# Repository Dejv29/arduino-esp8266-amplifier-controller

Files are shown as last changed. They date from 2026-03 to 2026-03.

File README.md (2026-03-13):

## **arduino-esp8266-amplifier-controller**  

Hybrid analog/digital amplifier controller with IR learning, motorized ALPS potentiometer feedback and ESP8266 web API.

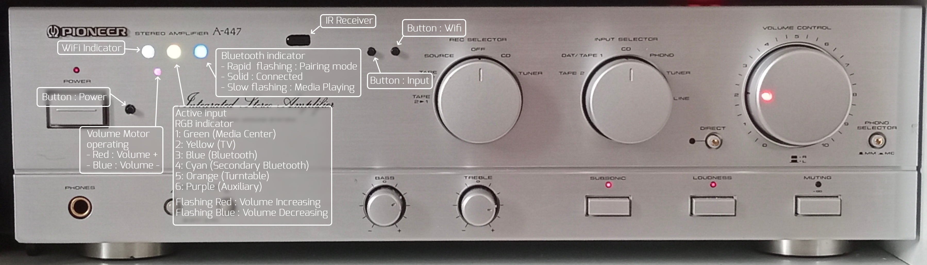
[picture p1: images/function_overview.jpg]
Amplifier


# **Arduino + ESP8266 Amplifier Controller**  

This project is a comprehensive control system for a classic analog amplifier built using an Arduino Nano and ESP8266. The goal was to preserve the original analog character of the amplifier (including manual volume control) while adding modern features such as IR control, a web interface, a remote terrace panel, and a network API.  

The module is designed as an upgrade for a previous system based on the CD4017N microcontroller. The PCB is connected to a socket in place of the CD4017N.

### **Architecture**

The system is divided into two parts:  

#### **Arduino Nano**  

- Control of the ALPS motorized potentiometer (volume)  

- Reading the current position of the rotary volume knob via an analog input (with an added trim potentiometer for feedback)  

- IR receiver with the ability to learn up to 10 codes for each function (stored in EEPROM)  

- Control of input relays and speaker switching relays  

- RGB LED indication of the currently selected input  

#### **ESP8266**

- Web server with configuration and control interface  

- HTTP API for external control  

- Serial communication with the Arduino  

Both parts operate independently – a WiFi outage does not affect the basic functionality of the amplifier.  

### **Features**

#### **IR Learning (EEPROM)**  

Each function can have up to 10 different IR codes assigned:  

- Volume +  
- Volume -  
- Power  
- Input  
- Speakers  
- Media Play/Pause  
- Media Next  
- Media Previous  

This allows multiple remote controls to be used simultaneously.  

#### **Volume – Hybrid Solution**  

An ALPS motorized potentiometer is used.  

Analog position sensing has been added, which means:  

- the volume can be adjusted by the motor (IR, web, HW buttons)  
- it can also be changed manually by turning the knob  
- the Arduino always knows the current physical position  

This preserves full analog functionality while adding digital control.  

#### **Audio Inputs**  

- 6 inputs  
- RGB LED indicates the active input  
- Input 3 contains an internal Bluetooth module  
- Input 4 contains an external Bluetooth module located in the terrace panel  

Each input can have an individual maximum volume limit set to prevent speaker overload when different signal levels are used.  

#### **Speaker Switching**  

The **Speakers** function switches between:  

- Living room speakers  
- Terrace speakers  

#### **Terrace Control Panel**  

The external panel includes:  

- Hardware buttons for all functions  
- A rotary volume control  
- An IR receiver  

The amplifier can therefore be fully controlled even outside the main room.  

#### **Web Interface (ESP8266)**  

The ESP8266 runs a simple web server that allows:  

- Control of all amplifier functions  
- Learning and deleting IR codes  
- Setting maximum volume limits for individual inputs  
- Displaying the current device status  

#### **HTTP API**  

The server accepts commands in the following format:  

SET_POWER_ON / SET_POWER_OFF  

SET_VOLUME_25  

SET_INPUT_2  

SET_SPEAKER_A / SET_SPEAKER_B  

PULSE_VOLUP  

PULSE_VOLDOWN  

SET_AUTO_OFF_<value_in_seconds> / SET_AUTO_OFF_0 – cancels the timer  

IR_LEARN_POWER (VOLUP, VOLDOWN, INPUT, SPEAKERS, PLAY, NEXT, PREV)  

IR_REMOVE_POWER (VOLUP, VOLDOWN, INPUT, SPEAKERS, PLAY, NEXT, PREV )  

IR_REMOVE_POWER_ALL  

SET_MAX_VOL_INPUT__<volume_value>   (sets the specified volume value as the limit)

SET_CURRENT_MAX_VOLUME  (sets the current volume as the limit)

WIPE_EEPROM (clears the EEPROM memory)

Each request returns a response containing the complete current device status.  

This API can be easily integrated into other systems – for example into the **Tasker** app, where a simple control application using HTTP commands has been created.  

____________________________________________________________________________________________________________________________________________________________________________________________________________________________________________________________________________________________________________________________________________

# **Arduino + ESP8266 Amplifier Controller**  

Tento projekt je komplexní řídicí systém pro klasický analogový zesilovač postavený na Arduino Nano a  ESP8266. Cílem bylo zachovat původní analogový charakter zesilovače (včetně manuálního ovládání hlasitosti), ale doplnit jej o moderní funkce – IR ovládání, webové rozhraní, vzdálený panel na terase a síťové API. 

Modul je koncipován jako upgrade pro předchozí systém postavený na mikrokontroléru CD4017N. PCB je připojena do patice na místo CD4017N.

### **Architektura**

Systém je rozdělen na dvě části:  

#### **Arduino Nano**  

- Řízení motorizovaného potenciometru ALPS (hlasitost)  

- Snímání aktuální polohy otočného ovladače hlasitosti přes analogový vstup (přidaný trimr pro zpětnou vazbu)  

- IR přijímač s možností učení až 10 kódů na každou funkci (uloženo v EEPROM)  

- Ovládání relé vstupů a reproduktorových větví  

- RGB LED indikace aktuálního vstupu  

#### **ESP8266**

- Web server s konfiguračním a ovládacím rozhraním  

- HTTP API pro externí řízení  

- Sériová komunikace s Arduinem 

 Obě části fungují nezávisle – výpadek WiFi neovlivní základní funkčnost zesilovače.  

### **Funkce**

#### **IR učení (EEPROM)**  

Každé funkci lze přiřadit až 10 různých IR kódů:  

- Volume +  
- Volume -  
- Power  
- Input  
- Speakers  
- Media Play/Pause  
- Media Next  
- Media Previous  

To umožňuje používat více dálkových ovladačů současně.  

#### **Hlasitost – hybridní řešení**  

Použit je motorizovaný potenciometr ALPS.  

   Bylo doplněno analogové snímání polohy, takže:  
- hlasitost lze měnit motorem (IR, web, HW tlačítka)  
- lze ji měnit i ručně otočením knobu  
- Arduino vždy zná aktuální fyzickou polohu

 Zachována je tedy plná analogová funkčnost, ale s digitální kontrolou.  

#### **Audio vstupy**  

- 6 vstupů  
- RGB LED indikuje aktivní vstup  
- Na vstupu 3 je interní Bluetooth modul  
- Na vstupu 4 je externí Bluetooth modul umístěný v terasovém panelu  

 Pro každý vstup lze nastavit individuální maximální limit hlasitosti, aby nedošlo k přetížení reproduktorů při různých úrovních signálu.  

#### **Přepínání reproduktorů**  

Funkce **Speakers** přepíná mezi:  

- Reproduktory v obýváku  
- Reproduktory na terase  

#### **Terasový ovládací panel**  

Externí panel obsahuje:  

- HW tlačítka pro všechny funkce  
- Otočný ovladač hlasitosti  
- IR přijímač  

 Zesilovač je tedy plně ovladatelný i mimo hlavní místnost.  

#### **Webové rozhraní (ESP8266)**  

ESP8266 provozuje jednoduchý web server, který umožňuje:  

- Ovládání všech funkcí zesilovače  
- Učení a mazání IR kódů  
- Nastavení maximální hlasitosti pro jednotlivé vstupy  
- Zobrazení aktuálního stavu zařízení  

#### **HTTP API**  

Server přijímá příkazy ve formátu:  

SET_POWER_ON / SET_POWER_OFF  

SET_VOLUME_25  

SET_INPUT_2  

SET_SPEAKER_A / SET_SPEAKER_B

PULSE_VOLUP  

PULSE_VOLDOWN  

SET_AUTO_OFF_<hodnota_v_sekundách> / SET_AUTO_OFF_0 – zruší časovač 

IR_LEARN_POWER (VOLUP, VOLDOWN, INPUT, SPEAKERS, PLAY, NEXT, PREV)  

IR_REMOVE_POWER (VOLUP, VOLDOWN, INPUT, SPEAKERS, PLAY, NEXT, PREV )  

IR_REMOVE_POWER_ALL  

SET_MAX_VOL_INPUT__<hodnota_volume>   (nastaví zadanou hodnotu hlasitosti jako limit)

SET_CURRENT_MAX_VOLUME  (nastaví současnou hlasitost jako limit)

WIPE_EEPROM (vymaže paměť EEPROM)

 Každý požadavek vrací odpověď obsahující kompletní aktuální stav zařízení.  

 Toto API lze snadno integrovat do jiných systémů – například do aplikace **Tasker**, kde je vytvořena jednoduchá ovládací aplikace využívající HTTP příkazy

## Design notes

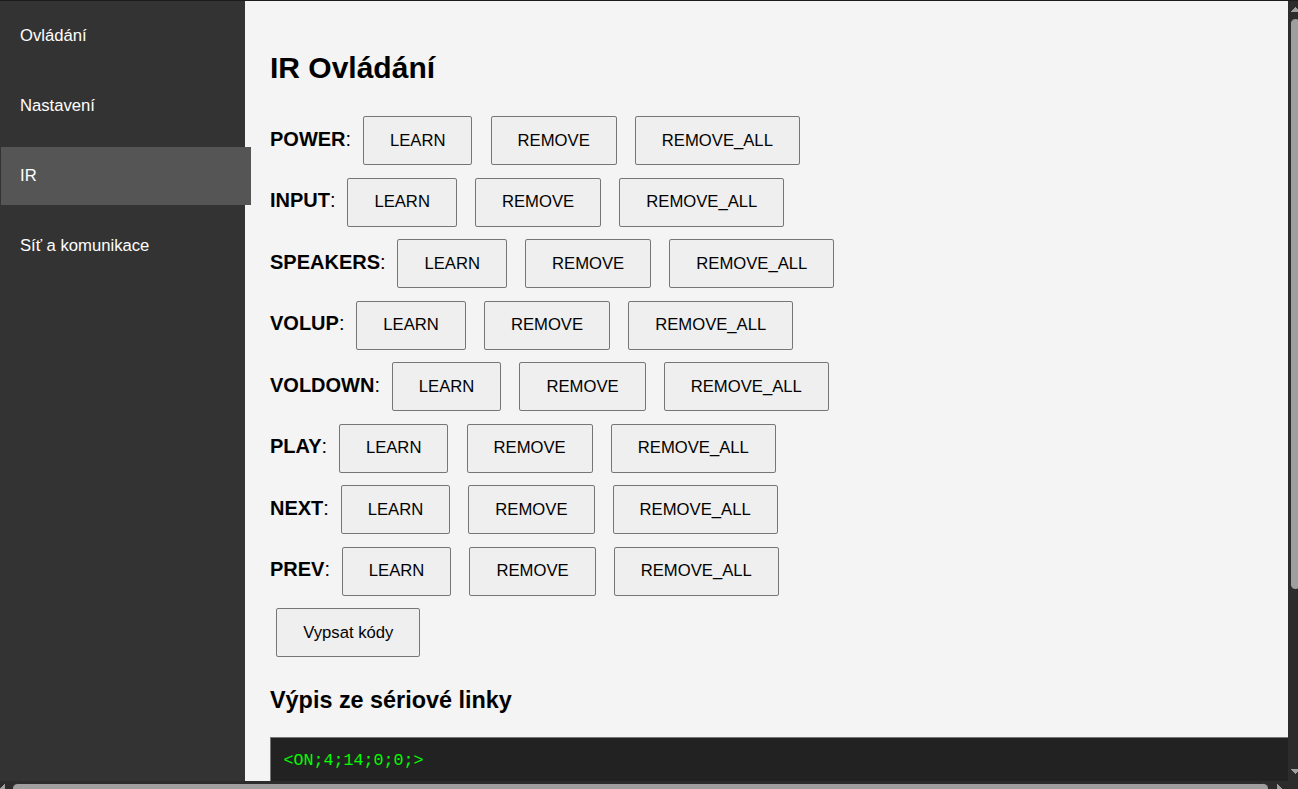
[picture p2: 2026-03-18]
images/web-ui_03.png

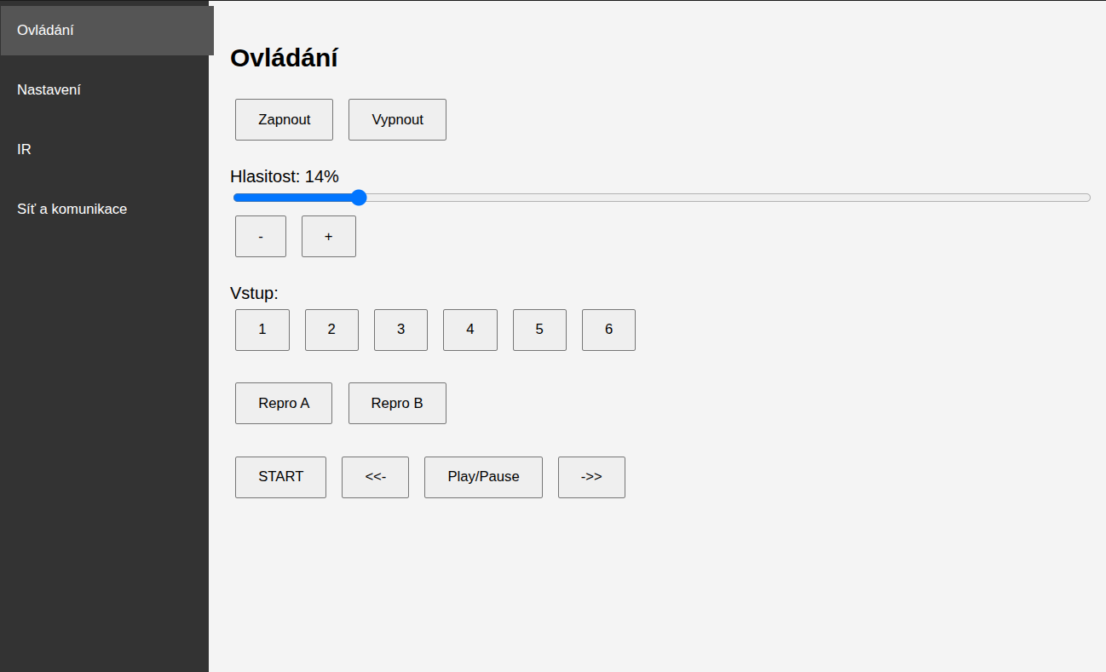
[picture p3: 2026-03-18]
images/web-ui_01.png

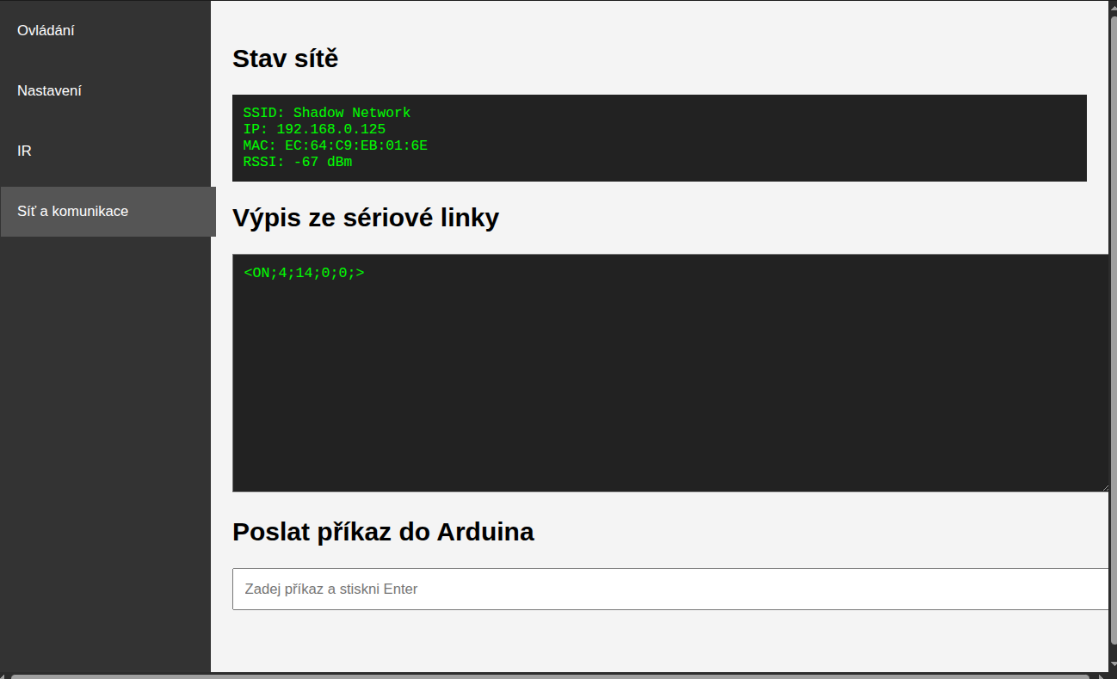
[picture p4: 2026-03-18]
images/web-ui_04.png

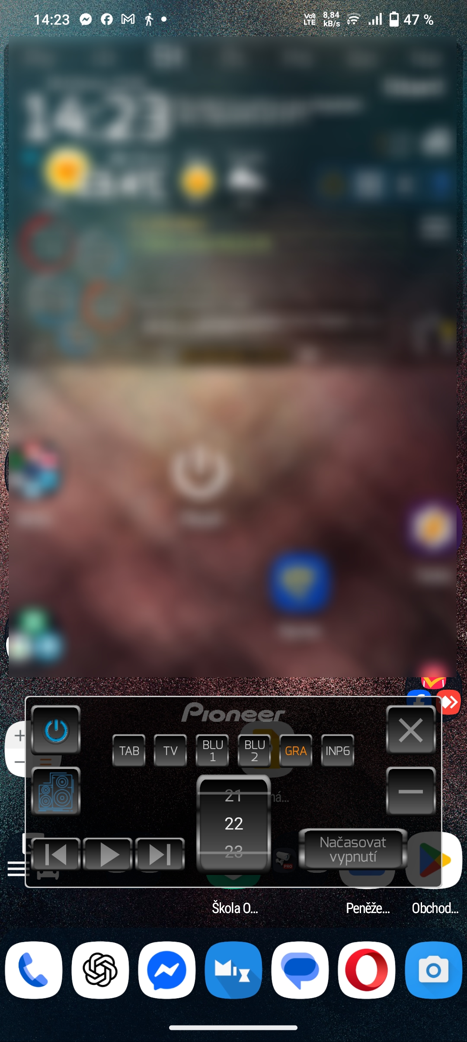
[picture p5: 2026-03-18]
images/tasker_control_ui.jpg

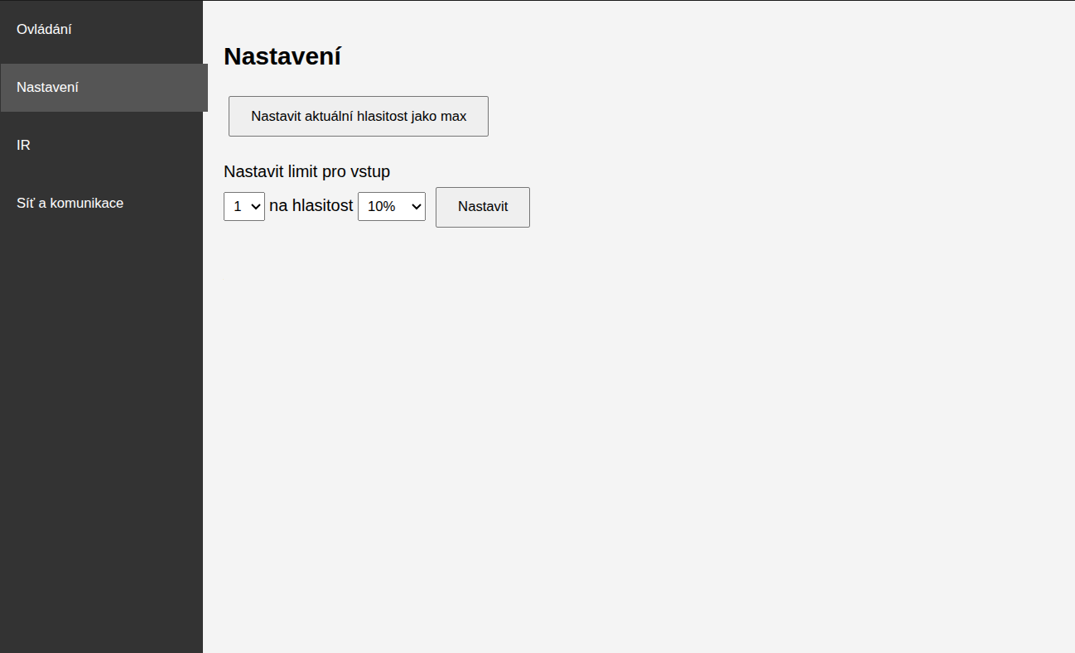
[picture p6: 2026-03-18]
images/web-ui_02.png

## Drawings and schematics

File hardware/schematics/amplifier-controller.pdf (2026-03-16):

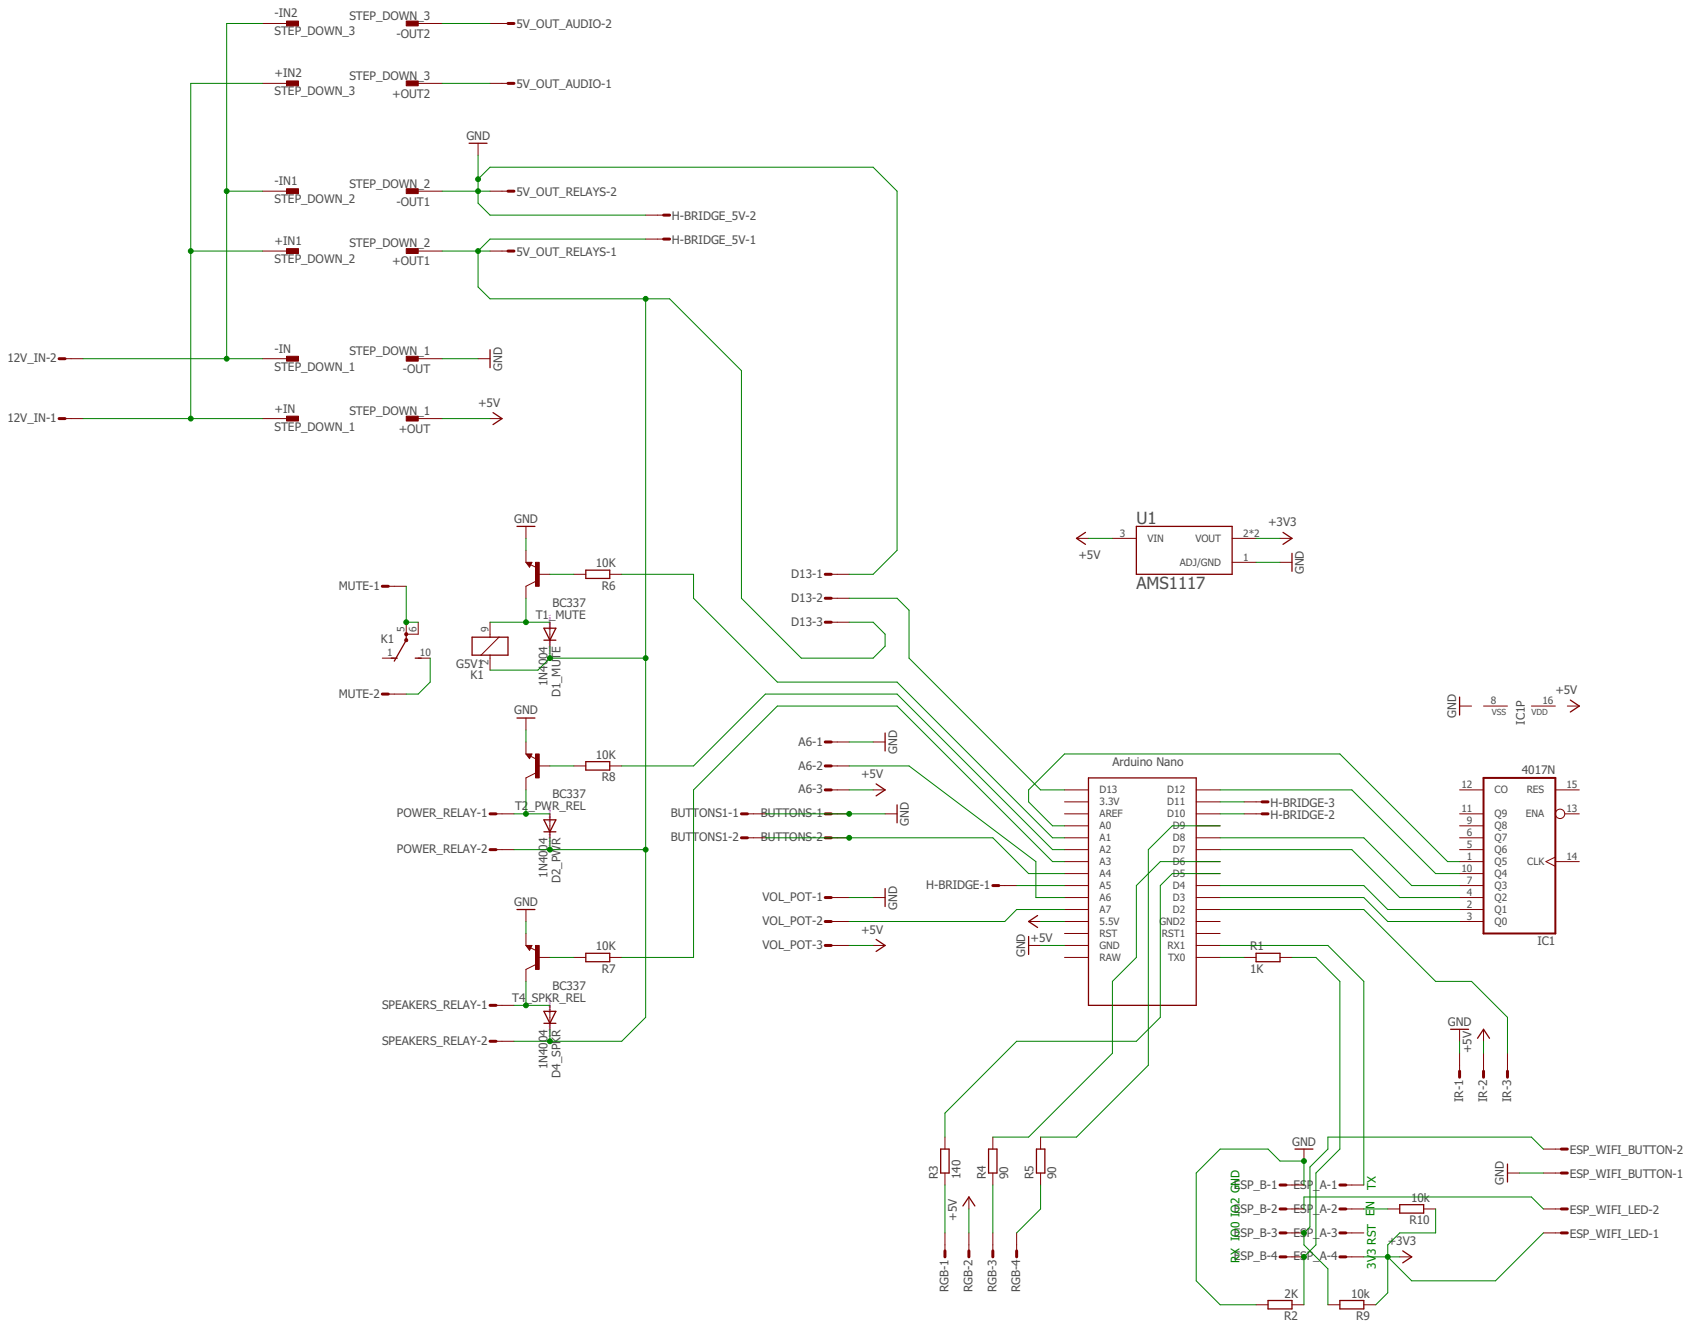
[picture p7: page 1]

SpiceOrder 1 SpiceOrder 2 SpiceOrder 1 SpiceOrder 2 SpiceOrder 1 SpiceOrder 2

RGB-1 RGB-2 RGB-3 RGB-4

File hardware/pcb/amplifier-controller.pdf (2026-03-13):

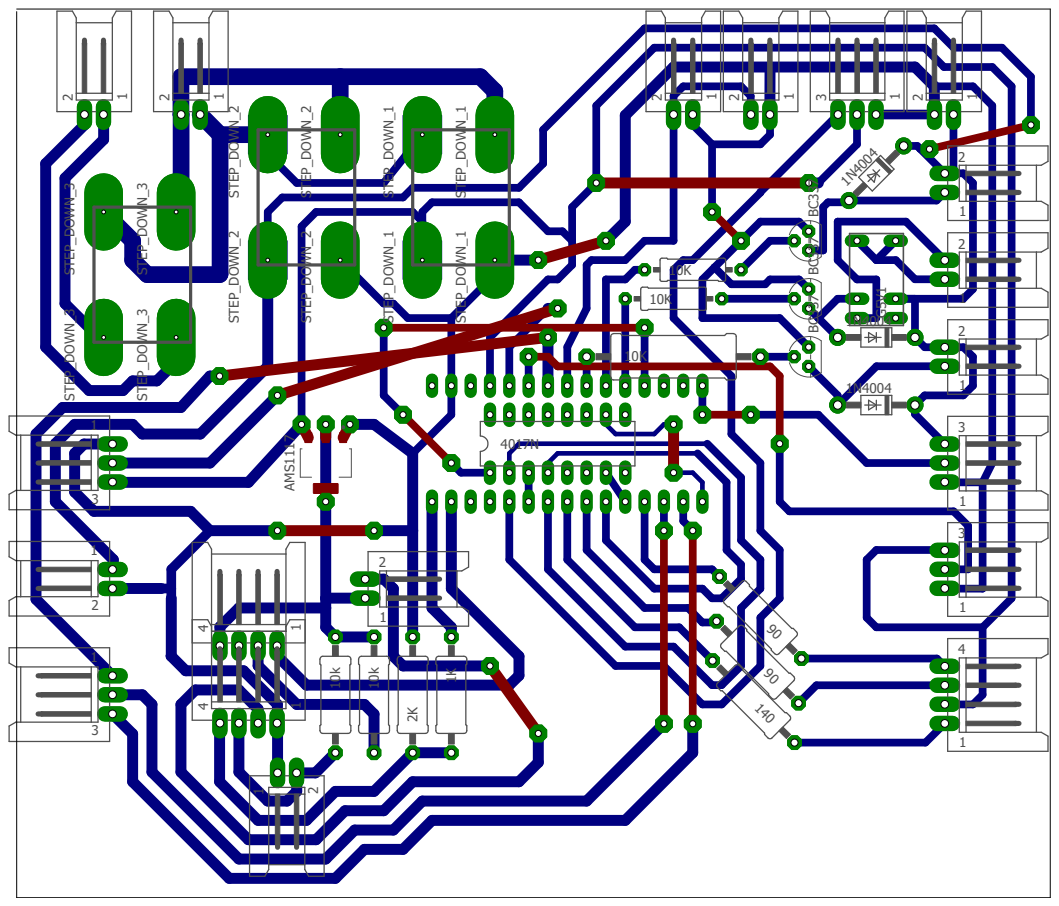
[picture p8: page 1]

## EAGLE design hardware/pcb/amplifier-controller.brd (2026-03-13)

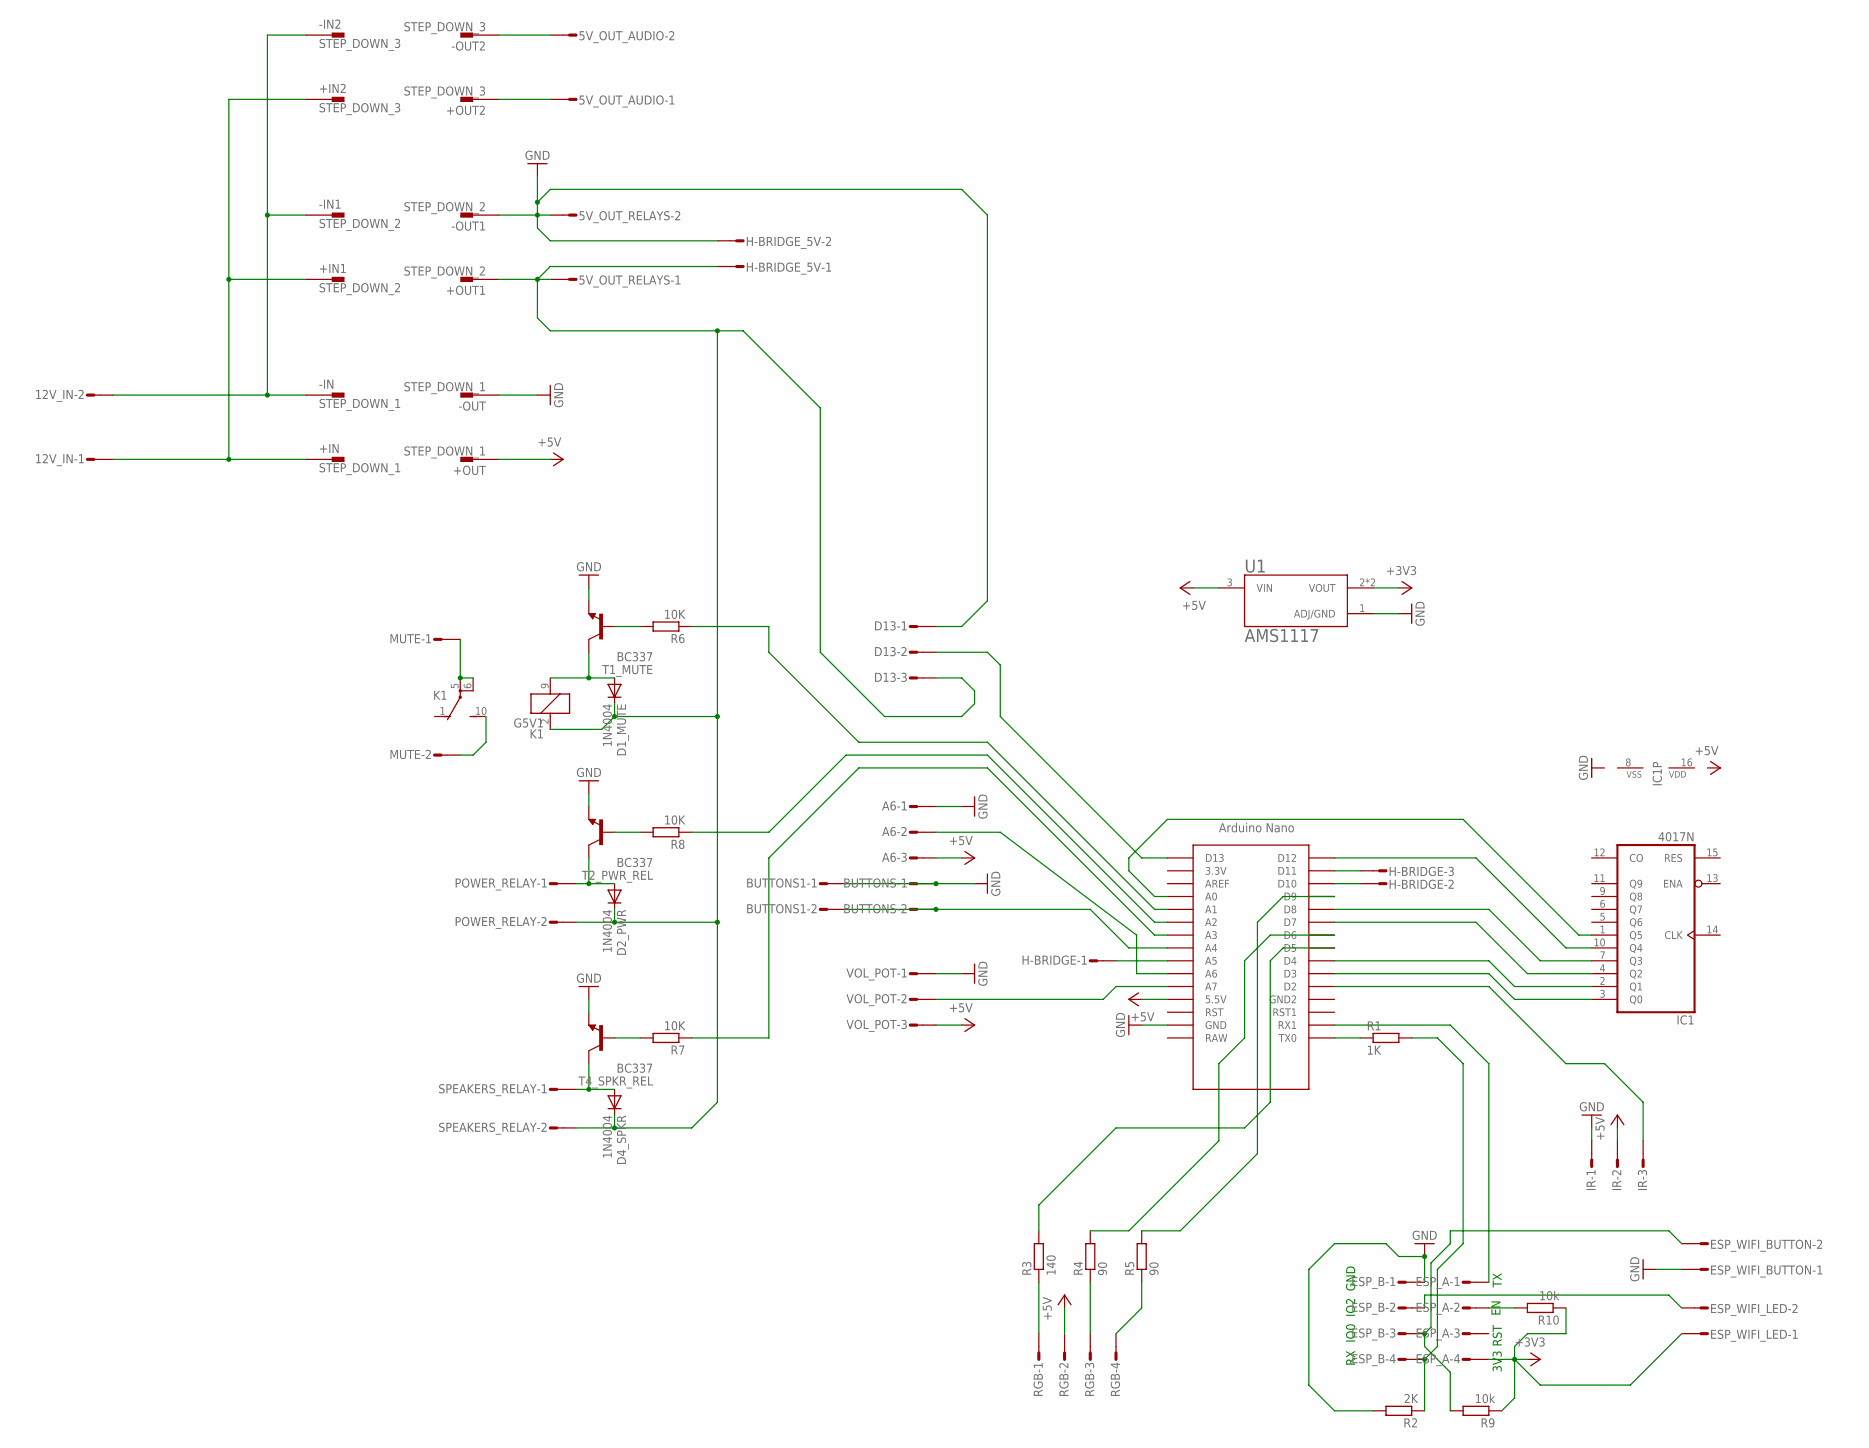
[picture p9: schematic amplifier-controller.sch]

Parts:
5V_OUT_AUDIO, 5V_OUT_RELAYS, 12V_IN: L02P
+IN: STEP_DOWN_1; 62221
+IN1: STEP_DOWN_2; 62221
+IN2: STEP_DOWN_3; 62221
+OUT: STEP_DOWN_1; 62221
+OUT1: STEP_DOWN_2; 62221
+OUT2: STEP_DOWN_3; 62221
-IN: STEP_DOWN_1; 62221
-IN1: STEP_DOWN_2; 62221
-IN2: STEP_DOWN_3; 62221
-OUT: STEP_DOWN_1; 62221
-OUT1: STEP_DOWN_2; 62221
-OUT2: STEP_DOWN_3; 62221
A6: L03P
BUTTONS, BUTTONS1: L02P
D1_MUTE, D2_PWR, D4_SPKR: 1N4004; DO41-10
D13: L03P
ESP_A: L04P
ESP_B: L04P
ESP_WIFI_BUTTON: L02P
ESP_WIFI_LED: L02P
H-BRIDGE: L03P
H-BRIDGE_5V: L02P
IC1: 4017N; DIL16
IR: L03P
K1: G5V1
MUTE: L02P
POWER_RELAY: L02P
R1: 1K; 0411/15
R2: 2K; 0411/15
R3: 140; 0411/15
R4, R5: 90; 0411/15
R6, R8: 10K; 0309/12
R7: 10K; 0617/22
R9, R10: 10k; 0411/15
RGB: L04P
SPEAKERS_RELAY: L02P
T1_MUTE, T2_PWR_REL, T4_SPKR_REL: BC337; TO92
U1: AMS1117; SOT229P700X180-4N
U$1: NANO
VOL_POT: L03P

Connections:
+3V3: ESP_A.4, ESP_WIFI_LED.1, R9.1, R10.1, U1.2 (VOUT), U1.4 (VOUT)
+5V: +OUT.1, A6.3, IR.2, RGB.2, U1.3 (VIN), U$1.5V (5.5V), VOL_POT.3
GND: 5V_OUT_RELAYS.2, -OUT.1, -OUT1.1, A6.1, BUTTONS.1, BUTTONS1.1, D13.1, ESP_B.1, ESP_WIFI_BUTTON.1, H-BRIDGE_5V.2, IR.1, R2.2, T1_MUTE.1 (E), T2_PWR_REL.1 (E), T4_SPKR_REL.1 (E), U1.1 (ADJ/GND), U$1.GND, VOL_POT.1
unnamed: ESP_B.4, R1.2, R2.1
unnamed: R1.1, U$1.TX0
unnamed: IR.3, U$1.D2
unnamed: IC1.3 (Q0), U$1.D3
unnamed: IC1.2 (Q1), U$1.D4
unnamed: IC1.4 (Q2), U$1.D7
unnamed: IC1.7 (Q3), U$1.D8
unnamed: IC1.10 (Q4), U$1.D12
unnamed: IC1.1 (Q5), U$1.A0
unnamed: H-BRIDGE.1, U$1.A5
unnamed: H-BRIDGE.2, U$1.D10
unnamed: H-BRIDGE.3, U$1.D11
unnamed: U$1.A7, VOL_POT.2
unnamed: BUTTONS.2, BUTTONS1.2, U$1.A4
unnamed: R3.1, RGB.1
unnamed: R4.1, RGB.3
unnamed: R5.1, RGB.4
unnamed: R3.2, U$1.D5
unnamed: R4.2, U$1.D6
unnamed: R5.2, U$1.D9
unnamed: D13.2, U$1.D13
unnamed: A6.2, U$1.A6
unnamed: ESP_B.3, ESP_WIFI_BUTTON.2, R9.2
unnamed: ESP_A.1, U$1.RX1
unnamed: D4_SPKR.A, SPEAKERS_RELAY.1, T4_SPKR_REL.3 (C)
unnamed: R7.2, T4_SPKR_REL.2 (B)
unnamed: R6.2, T1_MUTE.2 (B)
unnamed: R6.1, U$1.A1
unnamed: R7.1, U$1.A3
unnamed: D1_MUTE.A, K1.9 (2), T1_MUTE.3 (C)
unnamed: R8.2, T2_PWR_REL.2 (B)
unnamed: R8.1, U$1.A2
unnamed: D2_PWR.A, POWER_RELAY.1, T2_PWR_REL.3 (C)
unnamed: ESP_A.2, R10.2
unnamed: 12V_IN.2, -IN.1, -IN1.1, -IN2.1
unnamed: ESP_B.2, ESP_WIFI_LED.2
unnamed: 12V_IN.1, +IN.1, +IN1.1, +IN2.1
unnamed: K1.5, K1.6, MUTE.1
unnamed: K1.10 (S), MUTE.2
unnamed: 5V_OUT_AUDIO.1, +OUT2.1
unnamed: 5V_OUT_AUDIO.2, -OUT2.1
unnamed: 5V_OUT_RELAYS.1, +OUT1.1, D1_MUTE.C, D2_PWR.C, D4_SPKR.C, D13.3, H-BRIDGE_5V.1, K1.2 (1), POWER_RELAY.2, SPEAKERS_RELAY.2
VDD: IC1.16 (VDD)
VSS: IC1.8 (VSS)

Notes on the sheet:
3V3
RST
IO0
IO2
GND

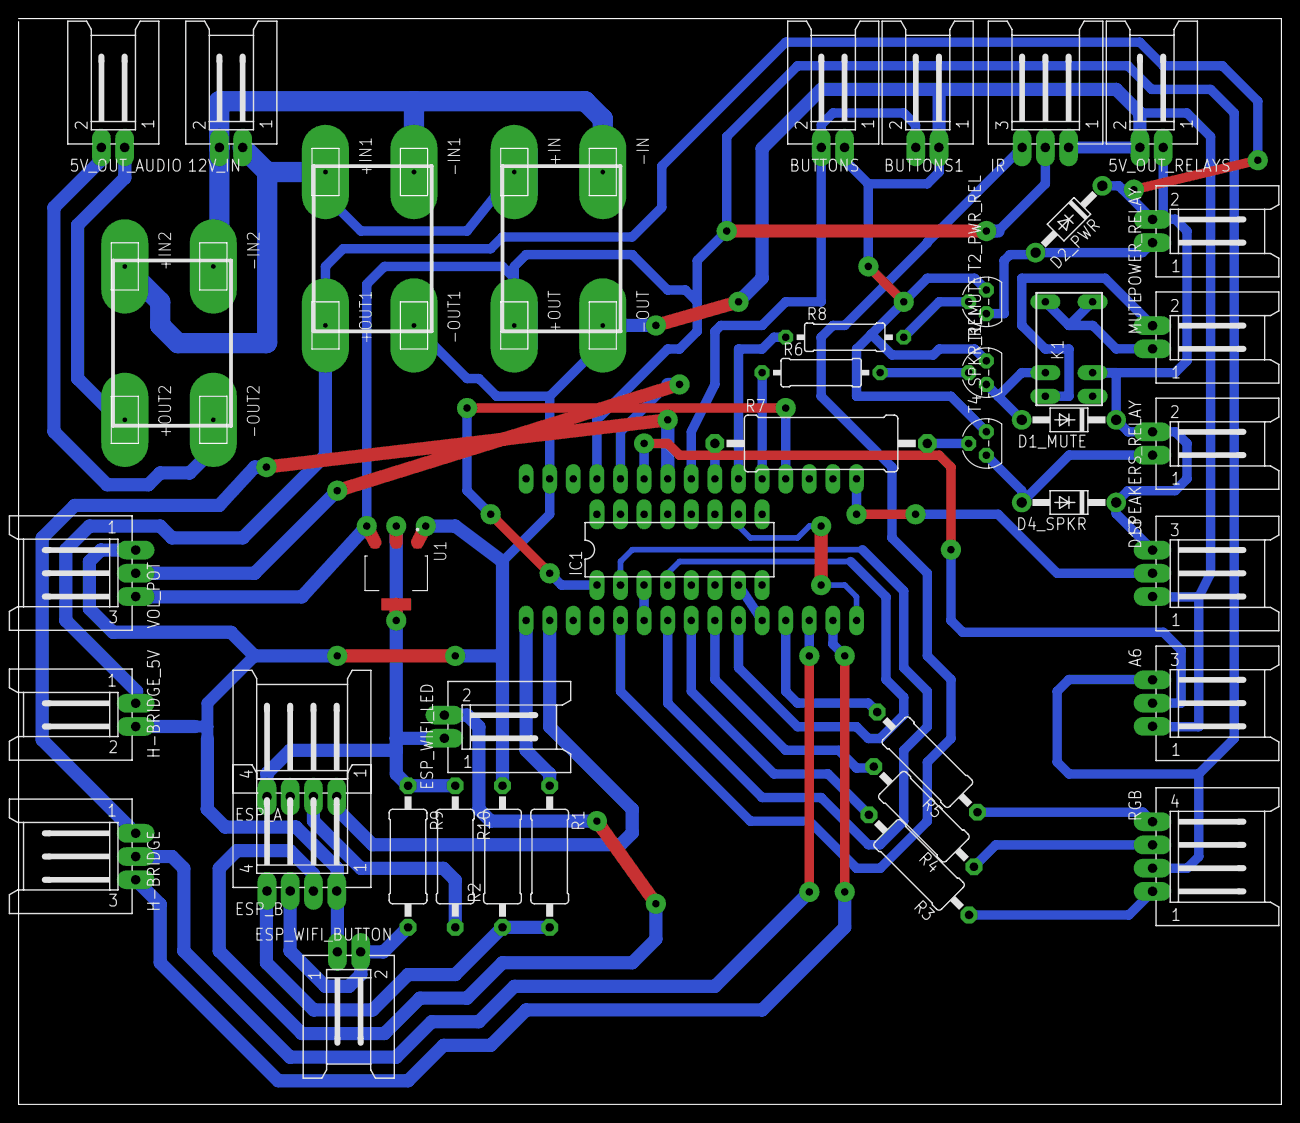
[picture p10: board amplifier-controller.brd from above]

Board: 2 copper layers, 135.9 x 116.8 mm, 51 parts (0 on the bottom side), 45 nets.

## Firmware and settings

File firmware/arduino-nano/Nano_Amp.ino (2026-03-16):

#include <IRremote.h>
#include <EEPROM.h>
#include <avr/wdt.h>





// === Piny ===
const int relayInputPins[6] = { 3, 4, 7, 8, 12, A0 };  // Vstupní relé
const int muteRelayPin = A1;
const int powerRelayPin = A2;
const int speakerRelayPin = A3;
const int pwmPin = 10;         // PWM výstup pro rychlost motoru
const int dirUpPin = 11;       // směr otáčení pro VOLUP
const int dirDownPin = A5;     // směr otáčení pro VOLDOWN
const int potPin = A7;

const int irReceiverPin = 2;

const int redPin = 5;
const int greenPin = 6;
const int bluePin = 9;

const int buttonPanelPin = A4;
//const int buttonTerracePin = A5;

int currentADC = 0;            // aktuální hodnota
int targetADC = 0;             // požadovaná hodnota (jen pro krátký stisk)
bool movingToTarget = false;   // zda se motor snaží dojet na cíl

// Zrychlování volume
unsigned long accelStartTime = 0;
const unsigned long accelDuration = 3000; // doba do maximální rychlosti
const int maxPWM = 255;
const int minPWM = 255;

//Krátké stisky volume
bool motorImpulseActive = false;
unsigned long motorImpulseEndTime = 0;
bool motorImpulseDirectionUp = true; // true = UP, false = DOWN

//Max volume
const int numInputs = 6;
int maxInputVol[numInputs];  // max. hlasitost v % pro každý vstup (0–100)
bool muteActive = false;

// Automaticke vypnuti po neaktivite
unsigned long lastActivity = 0;
const unsigned long autoOffTime = 3UL * 60UL * 60UL * 1000UL; // 3 hodiny

// Uzivatelsky casovac vypnuti
unsigned long timerEnd = 0;   // Čas, kdy má dojít k vypnutí
unsigned long timerRemaining = 0;  // Zbývajicí čas do vypnutí
bool timerActive = false;     // Jestli je časovač aktivní

// === IR Učení ===
const int maxIrCodes = 10;

unsigned long irCodesPower[maxIrCodes];
unsigned long irCodesVolUp[maxIrCodes];
unsigned long irCodesVolDown[maxIrCodes];
unsigned long irCodesSpeakers[maxIrCodes];
unsigned long irCodesInput[maxIrCodes];
unsigned long irCodesPlay[maxIrCodes];
unsigned long irCodesNext[maxIrCodes];
unsigned long irCodesPrev[maxIrCodes];

int irCountPower = 0;
int irCountVolUp = 0;
int irCountVolDown = 0;
int irCountSpeakers = 0;
int irCountInput = 0;
int irCountPlay = 0;
int irCountNext = 0;
int irCountPrev = 0;


enum IRLearnMode {
  IR_NONE,

  // Učení
  IR_LEARN_POWER,
  IR_LEARN_VOLUP,
  IR_LEARN_VOLDOWN,
  IR_LEARN_SPEAKERS,
  IR_LEARN_INPUT,
  IR_LEARN_PLAY,
  IR_LEARN_NEXT,
  IR_LEARN_PREV,

  // Odebrání jednoho
  IR_REMOVE_POWER,
  IR_REMOVE_VOLUP,
  IR_REMOVE_VOLDOWN,
  IR_REMOVE_SPEAKERS,
  IR_REMOVE_INPUT,
  IR_REMOVE_PLAY,
  IR_REMOVE_NEXT,
  IR_REMOVE_PREV,

  // Odebrání celé skupiny
  IR_REMOVE_POWER_ALL,
  IR_REMOVE_VOLUP_ALL,
  IR_REMOVE_VOLDOWN_ALL,
  IR_REMOVE_SPEAKERS_ALL,
  IR_REMOVE_INPUT_ALL,
  IR_REMOVE_PLAY_ALL,
  IR_REMOVE_NEXT_ALL,
  IR_REMOVE_PREV_ALL
};

IRLearnMode currentIRLearnMode = IR_NONE;

unsigned long irLearnStartTime = 0;
const unsigned long irLearnTimeout = 10000; // 10 sekund




// Kalibrace hlasitosti
int adcMin = 1;   // Hodnota pro 0 % (30)
int adcMax = 1023;  // Hodnota pro 100 % (991)

const int tolerance = 5;      // kolik jednotek může být od cíle, abychom považovali za dosažení


int volumePosition = 0;  // Startovní pozice



// === Stavové proměnné ===
bool powerState = false;
int activeInput = 0;  // 0 až 5
bool speakerState = false;
bool targetReached = false;   // true = motor se nepohybuje, stav dosažení cíle
bool poweringUp = false;
unsigned long powerOnTime = 0;


unsigned long muteEndTime = 0;

unsigned long lastPulseTime = 0;
bool pulseState = false;
const unsigned long pulseInterval = 250;  // 250 ms náběh/pád = 500 ms cyklus






// === Tlačítka ===
enum Button { BTN_NONE,
              BTN_POWER,
              BTN_INPUT,
              BTN_SPEAKERS,
              BTN_VOLUP,
              BTN_VOLDOWN,
              BTN_PLAY,
              BTN_NEXT,
              BTN_PREV };

              
// IR stisk
unsigned long irPressStartTime = 0;
bool irButtonHeld = false;
unsigned long lastIrReceiveTime = 0;
const unsigned long irHoldThreshold = 400;
const unsigned long irRepeatThreshold = 120;
Button lastIrButton = BTN_NONE;
bool irActionTaken = false;


// Short pulse
bool shortPulseActive = false;
unsigned long shortPulseStartTime = 0;
Button shortPulseButton = BTN_NONE;
const unsigned long shortPulseDuration = 250;

unsigned long volumeCurrentDelay = 50;   // výchozí prodleva (pomalejší začátek)
const unsigned long volumeMinDelay = 20;  // nejrychlejší krokování
const float volumeAccelFactor = 0.97;     // násobek pro zrychlování (čím menší, tím rychlejší zrychlení)


unsigned long lastStepTime = 0;
const int volumeStepDelay = 30;      // rychlost krokování v ms
bool volumeButtonHeld = false;       // příznak, že držíme tlačítko pro volume
Button heldVolumeButton = BTN_NONE;  // který tlačítko držíme

bool buttonActionTaken = false;



// Tačítka (přes dělič odporů)
Button getButtonFromADC(int adcVal) {
  //Serial.println(adcVal);
  //delay(1000);
  if (adcVal < 100) return BTN_POWER; // 330r
  if (adcVal < 150) return BTN_INPUT; // 1K45
  if (adcVal < 240) return BTN_SPEAKERS; // 2K7
  if (adcVal < 340) return BTN_VOLUP; // 4K7
  if (adcVal < 430) return BTN_VOLDOWN; // 6K7
  if (adcVal < 480) return BTN_PLAY; // 8K2
  if (adcVal < 530) return BTN_NEXT; // 10K
  if (adcVal < 580) return BTN_PREV; // 12K
  return BTN_NONE;
}

// === Časování pro rozlišení stisku ===
unsigned long buttonPressTime = 0;
bool buttonHeld = false;
Button lastButton = BTN_NONE;
const unsigned long longPressThreshold = 400;

void calibratePotentiometer() {
  Serial.println(F("Spouštím časovou kalibraci potenciometru..."));

  int midPWM = 255;//(minPWM + maxPWM) / 2

  // --- 1. Směr Volume UP (adc roste) ---
  Serial.println(F("Kalibrace horní meze (volume UP)..."));
  digitalWrite(dirDownPin, LOW);
  delay(100);
  digitalWrite(dirUpPin, HIGH);
  analogWrite(pwmPin, midPWM);

  unsigned long startTime = millis();
  int lastADC = analogRead(potPin);
  while (millis() - startTime < 14000) {
    int adc = analogRead(potPin);
    if (adc >= 1023) {
      Serial.println(F("Dosaženo ADC = 1023 (předčasné zastavení)"));
      break;
    }
    lastADC = adc;
    delay(10);
  }
  stopMotor();
  adcMax = lastADC;
  Serial.print(F("adcMax = "));
  Serial.println(adcMax);

  delay(500);

  // --- 2. Směr Volume DOWN (adc klesá) ---
  Serial.println(F("Kalibrace dolní meze (volume DOWN)..."));
  digitalWrite(dirUpPin, LOW);
  delay(100);
  digitalWrite(dirDownPin, HIGH);
  analogWrite(pwmPin, midPWM);

  startTime = millis();
  lastADC = analogRead(potPin);
  while (millis() - startTime < 14000) {
    int adc = analogRead(potPin);
    if (adc <= 0) {
      Serial.println(F("Dosaženo ADC = 0 (předčasné zastavení)"));
      break;
    }
    lastADC = adc;
    delay(10);
  }
  stopMotor();
  adcMin = lastADC;
  Serial.print(F("adcMin = "));
  Serial.println(adcMin);

  Serial.println(F("Kalibrace dokončena."));
}


// Kalibrace potenciomteru
void calibrateVolumePot() {
  stopMotor();
  digitalWrite(dirUpPin, HIGH);
  analogWrite(pwmPin, 255);
  delay(6000);
  stopMotor();
  adcMax = analogRead(potPin);

  digitalWrite(dirDownPin, HIGH);
  analogWrite(pwmPin, 255);
  delay(6000);
  stopMotor();
  adcMin = analogRead(potPin);

  Serial.print(F("Kalibrace dokončena: adcMin = "));
  Serial.print(adcMin);
  Serial.print(F(", adcMax = "));
  Serial.println(adcMax);
  }


// === WiFi komunikace ===
void checkWifiSerial() {
  while (Serial.available()) {
    char cmd[32];
    byte len = Serial.readBytesUntil('\n', cmd, sizeof(cmd) - 1);
    cmd[len] = '\0';
    int start = 0;
    while (cmd[start] == ' ' || cmd[start] == '\r' || cmd[start] == '\t') start++;
    int end = len - 1;
    while (end >= start && (cmd[end] == ' ' || cmd[end] == '\r' || cmd[end] == '\t')) {
      cmd[end] = '\0';
      end--;
    }
    if (start > 0) {
      for (int i = start; i <= end; i++) {
        cmd[i - start] = cmd[i];
      }
      cmd[end - start + 1] = '\0';
    }

    if (strcmp(cmd, "GET_POWER") == 0) {
      Serial.println(powerState ? "ON" : "OFF");

    } else if (strcmp(cmd, "SET_POWER_ON") == 0) {
      togglePower(true);

    } else if (strcmp(cmd, "SET_POWER_OFF") == 0) {
      togglePower(false);

    } else if (strncmp(cmd, "SET_INPUT_", 10) == 0) {
      if (!powerState) togglePower(true);
      int i = atoi(cmd + 10);
      if (i >= 0 && i < 6) {
        setInput(i);
        lastActivity = millis();
        //Serial.println("RESET HLAVNIHO CASOVACE");
      }

    } else if (strncmp(cmd, "SET_VOLUME_", 11) == 0) {
      if (!powerState) togglePower(true);
      int percent = atoi(cmd + 11);
      moveMotorToTarget(percent);
        lastActivity = millis();
        //Serial.println("RESET HLAVNIHO CASOVACE");

    } else if (strcmp(cmd, "GET_VOLUME_RAW") == 0) {
      int adc = analogRead(potPin);
      Serial.print(F("Volume RAW: "));
      Serial.println(adc);

    } else if (strcmp(cmd, "GET_VOLUME") == 0) {
      int volumePercent = getVolumePercent();
      Serial.print(F("Volume: "));
      Serial.print(volumePercent);
      Serial.println(F(" %"));

    } else if (strcmp(cmd, "SET_SPEAKER_A") == 0) {
      if (!powerState) togglePower(true);
      speakerState = false;
      digitalWrite(speakerRelayPin, LOW);
        lastActivity = millis();
        //Serial.println("RESET HLAVNIHO CASOVACE");

    } else if (strcmp(cmd, "SET_SPEAKER_B") == 0) {
      if (!powerState) togglePower(true);
      speakerState = true;
      digitalWrite(speakerRelayPin, HIGH);
        lastActivity = millis();
        //Serial.println("RESET HLAVNIHO CASOVACE");

    // IR LEARN
    } else if (strcmp(cmd, "IR_LEARN_POWER") == 0) {
      currentIRLearnMode = IR_LEARN_POWER;
      irLearnStartTime = millis();
      Serial.println(F("IR learning: POWER"));

    } else if (strcmp(cmd, "IR_LEARN_VOLUP") == 0) {
      currentIRLearnMode = IR_LEARN_VOLUP;
      irLearnStartTime = millis();
      Serial.println(F("IR learning: VOLUP"));

    } else if (strcmp(cmd, "IR_LEARN_VOLDOWN") == 0) {
      currentIRLearnMode = IR_LEARN_VOLDOWN;
      irLearnStartTime = millis();
      Serial.println(F("IR learning: VOLDOWN"));

    } else if (strcmp(cmd, "IR_LEARN_SPEAKERS") == 0) {
      currentIRLearnMode = IR_LEARN_SPEAKERS;
      irLearnStartTime = millis();
      Serial.println(F("IR learning: SPEAKERS"));

    } else if (strcmp(cmd, "IR_LEARN_INPUT") == 0) {
      currentIRLearnMode = IR_LEARN_INPUT;
      irLearnStartTime = millis();
      Serial.println(F("IR learning: INPUT"));

    // IR REMOVE
    } else if (strcmp(cmd, "IR_REMOVE_POWER") == 0) {
      currentIRLearnMode = IR_REMOVE_POWER;
      irLearnStartTime = millis();
      Serial.println(F("IR remove mode: POWER"));

    } else if (strcmp(cmd, "IR_REMOVE_VOLUP") == 0) {
      currentIRLearnMode = IR_REMOVE_VOLUP;
      irLearnStartTime = millis();
      Serial.println(F("IR remove mode: VOLUP"));

    } else if (strcmp(cmd, "IR_REMOVE_VOLDOWN") == 0) {
      currentIRLearnMode = IR_REMOVE_VOLDOWN;
      irLearnStartTime = millis();
      Serial.println(F("IR remove mode: VOLDOWN"));

    } else if (strcmp(cmd, "IR_REMOVE_SPEAKERS") == 0) {
      currentIRLearnMode = IR_REMOVE_SPEAKERS;
      irLearnStartTime = millis();
      Serial.println(F("IR remove mode: SPEAKERS"));

    } else if (strcmp(cmd, "IR_REMOVE_INPUT") == 0) {
      currentIRLearnMode = IR_REMOVE_INPUT;
      irLearnStartTime = millis();
      Serial.println(F("IR remove mode: INPUT"));

    } else if (strcmp(cmd, "CALIBRATE_POT") == 0) {
      togglePower(false);
      calibratePotentiometer();
      //calibrateVolumePot();
      togglePower(true);
      moveMotorToTarget(22);

    } else if (strcmp(cmd, "IR_PRINT") == 0) {
      printStoredIRCodes();

    } else if (strcmp(cmd, "IR_REMOVE_POWER_ALL") == 0) {
      clearIRGroup(IR_REMOVE_POWER_ALL);

    } else if (strcmp(cmd, "IR_REMOVE_VOLUP_ALL") == 0) {
      clearIRGroup(IR_REMOVE_VOLUP_ALL);

    } else if (strcmp(cmd, "IR_REMOVE_VOLDOWN_ALL") == 0) {
      clearIRGroup(IR_REMOVE_VOLDOWN_ALL);

    } else if (strcmp(cmd, "IR_REMOVE_SPEAKERS_ALL") == 0) {
      clearIRGroup(IR_REMOVE_SPEAKERS_ALL);

    } else if (strcmp(cmd, "IR_REMOVE_INPUT_ALL") == 0) {
      clearIRGroup(IR_REMOVE_INPUT_ALL);

    } else if (strcmp(cmd, "PULSE_VOLUP") == 0) {
      if (powerState) {
        shortPressVolUp();
        lastActivity = millis();
        //Serial.println("RESET HLAVNIHO CASOVACE");
        }

    } else if (strcmp(cmd, "PULSE_VOLDOWN") == 0) {
      if (powerState) {
        shortPressVolDown();
        lastActivity = millis();
        //Serial.println("RESET HLAVNIHO CASOVACE");
      }

    } else if (strncmp(cmd, "SET_MAX_VOL_INPUT_", 18) == 0) {
      int input = cmd[18] - '0';      // např. '3' → 3
      int percent = atoi(cmd + 20);  // např. SET_MAX_VOL_INPUT_3_60
        if (input >= 0 && input < numInputs) {
        saveMaxVolumeLimit(input, percent);
      }

    } else if (strcmp(cmd, "SET_CURRENT_MAX_VOLUME") == 0) {
        if (!powerState) {
      Serial.println(F("Cannot set max volume: system is OFF."));
      } else {
      currentADC = analogRead(potPin);
      int percent = map(currentADC, adcMin, adcMax, 0, 100);
      percent = constrain(percent, 0, 100);
      saveMaxVolumeLimit(activeInput, percent);
      Serial.print(F("Max volume limit for input "));
      Serial.print(activeInput);
      Serial.print(F(" set to current value: "));
      Serial.print(percent);
      Serial.println(F("%"));
      }
    } else if (strcmp(cmd, "IR_LEARN_PLAY") == 0) {
      currentIRLearnMode = IR_LEARN_PLAY;
      irLearnStartTime = millis();
      Serial.println(F("IR learning: PLAY"));

    } else if (strcmp(cmd, "IR_LEARN_NEXT") == 0) {
      currentIRLearnMode = IR_LEARN_NEXT;
      irLearnStartTime = millis();
      Serial.println(F("IR learning: NEXT"));

    } else if (strcmp(cmd, "IR_LEARN_PREV") == 0) {
      currentIRLearnMode = IR_LEARN_PREV;
      irLearnStartTime = millis();
      Serial.println(F("IR learning: PREV"));

    } else if (strcmp(cmd, "IR_REMOVE_PLAY") == 0) {
      currentIRLearnMode = IR_REMOVE_PLAY;
      irLearnStartTime = millis();
      Serial.println(F("IR remove mode: PLAY"));

    } else if (strcmp(cmd, "IR_REMOVE_NEXT") == 0) {
      currentIRLearnMode = IR_REMOVE_NEXT;
      irLearnStartTime = millis();
      Serial.println(F("IR remove mode: NEXT"));

    } else if (strcmp(cmd, "IR_REMOVE_PREV") == 0) {
      currentIRLearnMode = IR_REMOVE_PREV;
      irLearnStartTime = millis();
      Serial.println(F("IR remove mode: PREV"));

    } else if (strcmp(cmd, "IR_REMOVE_PLAY_ALL") == 0) {
      clearIRGroup(IR_REMOVE_PLAY_ALL);

    } else if (strcmp(cmd, "IR_REMOVE_PREV_ALL") == 0) {
      clearIRGroup(IR_REMOVE_PREV_ALL);

    } else if (strcmp(cmd, "IR_REMOVE_NEXT_ALL") == 0) {
      clearIRGroup(IR_REMOVE_NEXT_ALL);

    } else if (strcmp(cmd, "MEDIA_PLAY") == 0) {
      Serial.println(F("SEND_MEDIA_PLAY"));
        lastActivity = millis();
        analogWrite(redPin, 255);
      analogWrite(greenPin, 255);
      analogWrite(bluePin, 255);
        delay(80);
      analogWrite(redPin, 0);
      analogWrite(greenPin, 0);
      analogWrite(bluePin, 0);
        delay(120);
      analogWrite(redPin, 255);
      analogWrite(greenPin, 255);
      analogWrite(bluePin, 255);
        delay(500);
      updateRGB();

    } else if (strcmp(cmd, "MEDIA_START") == 0) {
      Serial.println(F("SEND_MEDIA_START"));
        lastActivity = millis();
        analogWrite(redPin, 255);
      analogWrite(greenPin, 255);
      analogWrite(bluePin, 255);
        delay(80);
      analogWrite(redPin, 0);
      analogWrite(greenPin, 0);
      analogWrite(bluePin, 0);
        delay(120);
      analogWrite(redPin, 255);
      analogWrite(greenPin, 255);
      analogWrite(bluePin, 255);
        delay(80);
        analogWrite(redPin, 0);
      analogWrite(greenPin, 0);
      analogWrite(bluePin, 0);
        delay(120);
        analogWrite(redPin, 255);
      analogWrite(greenPin, 255);
      analogWrite(bluePin, 255);
        delay(500);
      updateRGB();

    } else if (strcmp(cmd, "MEDIA_PREV") == 0) {
      Serial.println(F("SEND_MEDIA_PREV"));
        lastActivity = millis();
        analogWrite(redPin, 255);
      analogWrite(greenPin, 255);
      analogWrite(bluePin, 255);
        delay(80);
      analogWrite(redPin, 0);
      analogWrite(greenPin, 0);
      analogWrite(bluePin, 0);
        delay(120);
      analogWrite(redPin, 255);
      analogWrite(greenPin, 255);
      analogWrite(bluePin, 255);
        delay(500);
      updateRGB();

    } else if (strcmp(cmd, "MEDIA_NEXT") == 0) {
      Serial.println(F("SEND_MEDIA_NEXT"));
        lastActivity = millis();
        analogWrite(redPin, 255);
      analogWrite(greenPin, 255);
      analogWrite(bluePin, 255);
        delay(80);
      analogWrite(redPin, 0);
      analogWrite(greenPin, 0);
      analogWrite(bluePin, 0);
        delay(120);
      analogWrite(redPin, 255);
      analogWrite(greenPin, 255);
      analogWrite(bluePin, 255);
        delay(500);
      updateRGB();

    } else if (strcmp(cmd, "WIPE_EEPROM") == 0) {
      wipeEEPROM();

    } else if (strncmp(cmd, "SET_AUTO_OFF_", 13) == 0) {
      // získáme číslo za prefixem
      long sec = atol(cmd + 13); // převede string na číslo (long)
      if (sec > 0) {
        setTimer(sec); // nastaví uživatelský časovač
        Serial.print("Auto-off set to ");
        Serial.print(sec);
        Serial.println(" seconds.");
       } else if (sec == 0) {
          setTimer(sec);
        
      } else {
        Serial.println("Invalid time for auto-off.");
      }
    }
    Serial.print(F("<"));
    Serial.print(powerState ? "ON;" : "OFF;");
    Serial.print(activeInput);
    Serial.print(F(";"));
    int volumePercent = getVolumePercent();
      Serial.print(volumePercent);
      Serial.print(F(";"));
    Serial.print(speakerState);
      if (timerActive) {
        timerRemaining = ((timerEnd - millis()) / 1000UL);
          }
      else {
        timerRemaining = 0;
      }
      Serial.print(F(";"));
      Serial.print(timerRemaining);
      Serial.println(F(";>"));
  }
}

#define EEPROM_MAGIC            0x42
#define EEPROM_VOLUME_MAGIC     0x99

#define EEPROM_ADDR_MAGIC       0
#define EEPROM_ADDR_IRDATA      1
#define EEPROM_ADDR_VOLUME_MAGIC 400
#define EEPROM_ADDR_VOLUME_LIMITS (EEPROM_ADDR_VOLUME_MAGIC + 1)


void saveIRCodesToEEPROM() {
  int addr = EEPROM_ADDR_IRDATA;
  EEPROM.update(EEPROM_ADDR_MAGIC, EEPROM_MAGIC);

  auto saveSet = [&](int count, unsigned long* codes) {
    EEPROM.update(addr++, count);
    for (int i = 0; i < count; i++) {
      EEPROM.put(addr, codes[i]);
      addr += sizeof(unsigned long);
    }
  };

  saveSet(irCountPower,    irCodesPower);
  saveSet(irCountVolUp,    irCodesVolUp);
  saveSet(irCountVolDown,  irCodesVolDown);
  saveSet(irCountSpeakers, irCodesSpeakers);
  saveSet(irCountInput,    irCodesInput);
  saveSet(irCountPlay,     irCodesPlay);
  saveSet(irCountNext,     irCodesNext);
  saveSet(irCountPrev,     irCodesPrev);
}

void loadIRCodesFromEEPROM() {
  if (EEPROM.read(EEPROM_ADDR_MAGIC) != EEPROM_MAGIC) {
    Serial.println(F("EEPROM není inicializováno platnými IR daty."));
    return;
  }

  int addr = EEPROM_ADDR_IRDATA;

  auto loadSet = [&](int& count, unsigned long* codes) {
    count = EEPROM.read(addr++);
    count = constrain(count, 0, maxIrCodes);
    for (int i = 0; i < count; i++) {
      EEPROM.get(addr, codes[i]);
      addr += sizeof(unsigned long);
    }
  };

  loadSet(irCountPower,    irCodesPower);
  loadSet(irCountVolUp,    irCodesVolUp);
  loadSet(irCountVolDown,  irCodesVolDown);
  loadSet(irCountSpeakers, irCodesSpeakers);
  loadSet(irCountInput,    irCodesInput);
  loadSet(irCountPlay,     irCodesPlay);
  loadSet(irCountNext,     irCodesNext);
  loadSet(irCountPrev,     irCodesPrev);

  Serial.println(F("IR kódy načteny z EEPROM."));
}

void saveMaxVolumeLimit(int input, int value) {
  if (input >= 0 && input < numInputs) {
    value = constrain(value, 0, 100);
    EEPROM.update(EEPROM_ADDR_VOLUME_LIMITS + input, value);
    maxInputVol[input] = value;
    EEPROM.update(EEPROM_ADDR_VOLUME_MAGIC, EEPROM_VOLUME_MAGIC);
    Serial.print(F("Uloženo maxVolumeLimit vstupu "));
    Serial.print(input);
    Serial.print(F(": "));
    Serial.println(value);
  }
}
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
void loop() {

  handleButtons();
  handleMute();
  checkWifiSerial();
  handleShortVolumeLedPulse();
  handleIRLearning();
  handleIRButtons();
  if(powerState && !poweringUp) {
    checkMaxVolLimit();
    }

  if (movingToTarget) {
  moveMotorToTarget();
}

if (poweringUp && millis() - powerOnTime >= 4000) {
  poweringUp = false;
}



if (volumeButtonHeld) {
    handleVolumeLedPulse();  // <- přidáno zde

    if (millis() - lastStepTime >= volumeCurrentDelay) {
      lastStepTime = millis();
      if (heldVolumeButton == BTN_VOLUP) {
        longPressVolUpLoop();
      } else if (heldVolumeButton == BTN_VOLDOWN) {
        longPressVolDownLoop();
      }
    }
  }



if (motorImpulseActive && millis() >= motorImpulseEndTime) {
  stopMotor();
  motorImpulseActive = false;
}

if (millis() - lastInputChange > brightDuration && lastInputChange != 0){
    lastInputChange = 0;
    updateRGB();
}

if (powerState && millis() - lastActivity >= autoOffTime) {
    Serial.println(F("3 hodiny neaktivity, vypínám zesilovač..."));
    togglePower(!powerState);
  }

//lastActivity = millis();
//Serial.println("RESET HLAVNIHO CASOVACE");

checkTimer();

  // Button btn = getButtonFromADC(analogRead(A4));
  // Serial.print(F("Button: "));
  // Serial.println(btn);
}

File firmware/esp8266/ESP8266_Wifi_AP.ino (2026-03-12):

#include <ESP8266WiFi.h>
#include <ESPAsyncTCP.h>
#include <ESPAsyncWebServer.h>
#include <EEPROM.h>
#include <ESP8266HTTPClient.h>
#include <WiFiClient.h>

#define BUTTON_PIN 0      // Tlačítko na GPIO0
#define LED_PIN    2      // Vestavěná LED na ESP-01 (GPIO2)
#define EEPROM_SIZE 96

unsigned long buttonPressTime = 0;
bool wasLongPressHandled = false;

char ssid[32] = "";
char password[64] = "";

AsyncWebServer server(80);
AsyncWebSocket ws("/ws");

String serialBuffer = "";
bool serialChanged = false;

bool inAPMode = false;

String waitForSerialResponse(unsigned long timeout = 1000) {
  String response = "";
  unsigned long start = millis();
  while (millis() - start < timeout) {
    while (Serial.available()) {
      response += Serial.readStringUntil('\n') + "\n";
    }
    if (response.length() > 0) break;
    delay(10);
  }
  return response.length() > 0 ? response : "Žádná odpověď ze sériové linky.";
}

String getNetworkStatus() {
  String status = "";
  status += "SSID: " + String(WiFi.SSID()) + "\n";
  status += "IP: " + WiFi.localIP().toString() + "\n";
  status += "MAC: " + WiFi.macAddress() + "\n";
  status += "RSSI: " + String(WiFi.RSSI()) + " dBm\n";
  return status;
}

void sendHttpCommand(const char* url) {
  WiFiClient client;
  HTTPClient http;

  if (http.begin(client, url)) {
    int httpCode = http.GET();
    if (httpCode > 0) {
      String payload = http.getString();
      Serial.println(payload);
    } else {
      Serial.printf("HTTP GET failed, error: %s\n", http.errorToString(httpCode).c_str());
    }
    http.end();
  } else {
    Serial.println("HTTP begin failed");
  }
}

void handleSerial() {
  while (Serial.available()) {
    String line = Serial.readStringUntil('\n');
    line.trim();  // odstraní \r a mezery

    if (line.length() > 0) {
      serialBuffer += line + "\n";
      serialChanged = true;

      // zpracování speciálních příkazů
      if (line == "SEND_MEDIA_PLAY") {
        sendHttpCommand("http://192.168.0.105:1817/?message=MediaPlay");
      }
      else if (line == "SEND_MEDIA_START") {
        sendHttpCommand("http://192.168.0.105:1817/?message=MediaStart");
      }
      else if (line == "SEND_MEDIA_PREV") {
        sendHttpCommand("http://192.168.0.105:1817/?message=MediaPrev");
      }
      else if (line == "SEND_MEDIA_NEXT") {
        sendHttpCommand("http://192.168.0.105:1817/?message=MediaNext");
      }
    }
  }
}

void notifyClients() {
  if (serialChanged && serialBuffer.length() > 0) {
    ws.textAll(serialBuffer);
    serialBuffer = "";
    serialChanged = false;
  }
}

const char index_html[] PROGMEM = R"rawliteral(
<!DOCTYPE html>
<html>
<head>
  <meta charset="utf-8">
  <title>ESP Ovládání</title>
  <style>
    body { font-family: sans-serif; margin: 0; background: #f4f4f4; }

    .tabs {
      display: flex;
      height: 100vh;
    }

    .tab-buttons {
      display: flex;
      flex-direction: column;
      width: 200px;
      background: #333;
    }

    .tab-buttons button {
      background: none;
      color: white;
      border: none;
      padding: 15px;
      text-align: left;
      cursor: pointer;
      width: 100%;
    }

    .tab-buttons button.active {
      background: #555;
    }

    .tab-content {
      flex: 1;
      padding: 20px;
      display: none;
    }

    .tab-content.active {
      display: block;
    }

    button { margin: 5px; padding: 10px 20px; }
    .group { margin-bottom: 20px; }

    pre, textarea {
      background: #222; color: #0f0; padding: 10px;
      font-family: monospace; white-space: pre-wrap;
    }

    textarea { width: 100%; height: 200px; resize: vertical; }
    input[type="text"] { width: 100%; padding: 10px; }
    select { padding: 5px; }
    input[type="range"] { width: 100%; }
  </style>
</head>
<body>

<div class="tabs">
  <div class="tab-buttons">
    <button onclick="showTab(0)" class="active">Ovládání</button>
    <button onclick="showTab(1)">Nastavení</button>
    <button onclick="showTab(2)">IR</button>
    <button onclick="showTab(3)">Síť a komunikace</button>
  </div>

  <div class="tab-content active">
    <h2>Ovládání</h2>
    <div class="group">
      <button onclick="sendCmd('SET_POWER_ON')">Zapnout</button>
      <button onclick="sendCmd('SET_POWER_OFF')">Vypnout</button>
    </div>

    <div>
      <label for="volume">Hlasitost: <span id="volumeLabel">50</span>%</label><br>
      <input type="range" id="volume" min="0" max="100" value="50">
      <div class="group">
        <button onclick="sendCmd('PULSE_VOLDOWN')">-</button>
        <button onclick="sendCmd('PULSE_VOLUP')">+</button>
      </div>
    </div>

    <div class="group">
      Vstup:<br>
      <button onclick="sendCmd('SET_INPUT_0')">1</button>
      <button onclick="sendCmd('SET_INPUT_1')">2</button>
      <button onclick="sendCmd('SET_INPUT_2')">3</button>
      <button onclick="sendCmd('SET_INPUT_3')">4</button>
      <button onclick="sendCmd('SET_INPUT_4')">5</button>
      <button onclick="sendCmd('SET_INPUT_5')">6</button>
    </div>

    <div class="group">
      <button onclick="sendCmd('SET_SPEAKER_A')">Repro A</button>
      <button onclick="sendCmd('SET_SPEAKER_B')">Repro B</button>
    </div>

    <div class="group">
      <button onclick="sendCmd('MEDIA_START')">START</button>
      <button onclick="sendCmd('MEDIA_PREV')"><<-</button>
      <button onclick="sendCmd('MEDIA_PLAY')">Play/Pause</button>
      <button onclick="sendCmd('MEDIA_NEXT')">->></button>
    </div>
  </div>

  <div class="tab-content">
    <h2>Nastavení</h2>
    <div class="group">
      <button onclick="sendCmd('SET_CURRENT_MAX_VOLUME')">Nastavit aktuální hlasitost jako max</button>
    </div>
    <div class="group">
      <label>Nastavit limit pro vstup</label><br>
      <select id="inputSelect">
        <option value="0">1</option><option value="1">2</option>
        <option value="2">3</option><option value="3">4</option>
        <option value="4">5</option><option value="5">6</option>
      </select>
      na hlasitost
      <select id="volSelect">
        <option value="10">10%</option><option value="20">20%</option>
        <option value="30">30%</option><option value="40">40%</option>
        <option value="50">50%</option><option value="60">60%</option>
        <option value="70">70%</option><option value="80">80%</option>
        <option value="90">90%</option><option value="100">100%</option>
      </select>
      <button onclick="setInputMaxVolume()">Nastavit</button>
    </div>
  </div>

  <div class="tab-content">
    <h2>IR Ovládání</h2>
    <div id="irButtons"></div>
    <button onclick="sendCmd('IR_PRINT')">Vypsat kódy</button>
    <h3>Výpis ze sériové linky</h3>
    <textarea id="serialLog1" readonly></textarea>
  </div>

  <div class="tab-content">
    <h2>Stav sítě</h2>
    <pre id="netStatus">Načítání...</pre>

    <h2>Výpis ze sériové linky</h2>
    <textarea id="serialLog2" readonly></textarea>
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

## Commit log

2026-03-12 Initial commit: Arduino amplifier controller
2026-03-13 Update README, added images, added PCB and schematics
    [amplifier-controller.brd, amplifier-controller.sch]
